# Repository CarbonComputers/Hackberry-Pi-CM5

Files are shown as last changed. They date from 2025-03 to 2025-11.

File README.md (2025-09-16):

<p align="center">
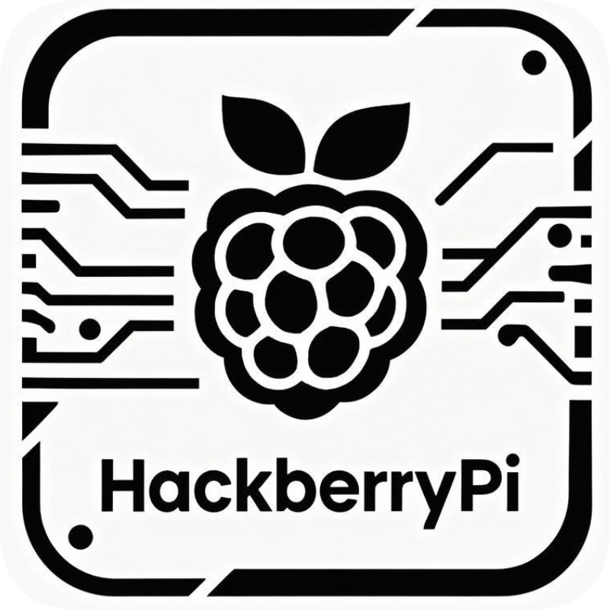
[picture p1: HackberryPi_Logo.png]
Redox logo

 </p>

 <h3 align="center">The HackberryPi_CM5 Project Repo</h3>

<div align="center">

[]()




</div>

---

The HackberryPi CM5 project is a Raspberry Pi Compute Module SBC(single board computer) powered handheld computer with reuse of original keyboard from old Blackberry phones. The goal of the project is to create a portable linux-powered computer that lets the user gain a deeper understanding of Linux and explore the architecture of hardware, software, and the Linux kernel. This repository will be used to share information about the project and tutorial about how to make use of this device.

<p align="center">
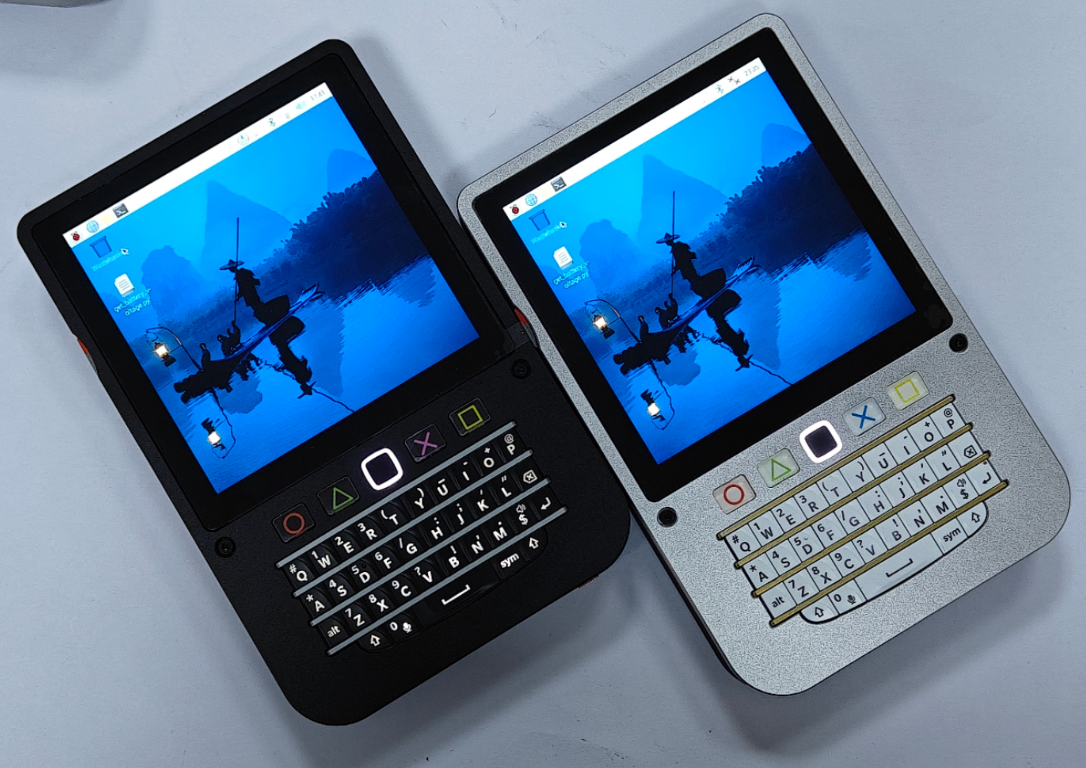
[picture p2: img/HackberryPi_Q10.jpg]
HackberryPi_CM5

</p>

**About the creator bio**: Zitao, currently a master’s student in Mechanical Engineering and Industrial Design at the Technical University of Dresden, Germany  

<div align="center">
 
[Questions or need more info? Join my Discord Channel!](https://discord.gg/WzPthAmMbP)
 
 </div>

  # <a name='Dimension and weight  '>Dimension and weight</a>
  **Overall dimensions:** 143.5x91.8x17.6mm  
  **Weight:** 306 Gramm(with battery,cm5 and heat sink)  
  Upper and lower case made of aluminium  
  Middle part 3d printed  
  <p align="center">
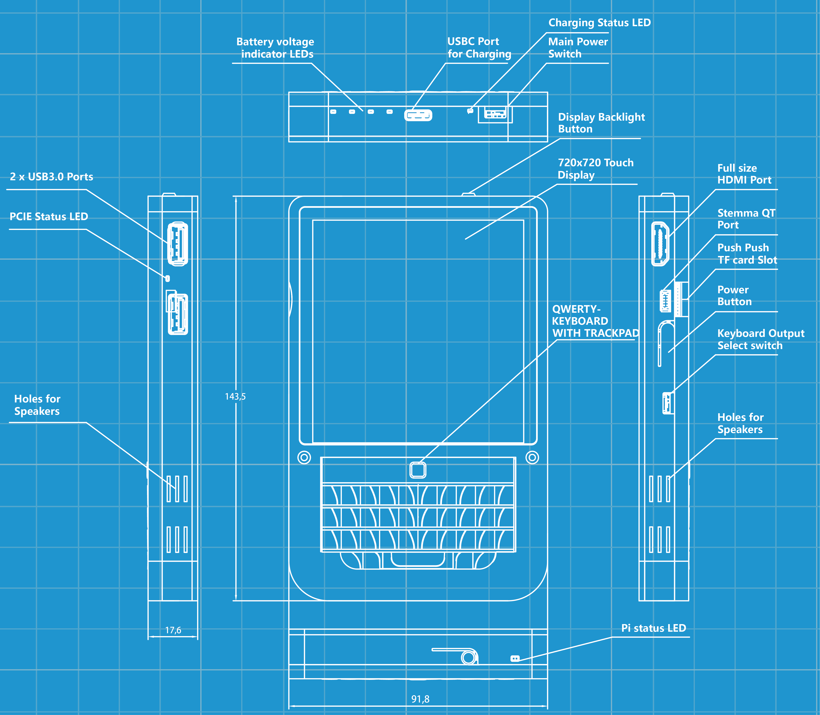
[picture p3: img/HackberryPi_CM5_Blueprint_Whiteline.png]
HackberryPi_CM5_Blueprint

 </p>
 And this is how it looks like inside the device:
  <p align="center">
HackberryPi_CM5_inside
 </p>
 
 # <a name='About this Device '>About this Device </a>

| **Feature** | **Details** |
|---|---|
| **SBC** | Only compatible with Raspberry Pi CM5. [CM5 Datasheet](https://datasheets.raspberrypi.com/cm5/cm5-datasheet.pdf) |
| **CPU** | BCM2712, quad-core Cortex-A76 (ARMv8) 64-bit SoC @ 2.4GHz |
| **Dual Speakers** | Dual speakers connected via Bluetooth. [More information](https://github.com/ZitaoTech/HackberryPiCM5/tree/main/Speakers) |
| **2242 NVME Slot** | Supports 2242 SSD or Halio AI accelerator card. [More information](https://github.com/ZitaoTech/HackberryPiCM5/tree/main/NVME%20Slot) |
| **RTC Battery** | CR927 battery slot for RTC functionality. [More information](https://github.com/ZitaoTech/HackberryPiCM5/tree/main/RTC-Battery) |
| **Metal Body** | Aluminium front and back plate; 3D-printed middle section |
| **Display** | 4" 720x720 high-resolution TFT with multi-touch |
| **USB Ports** | 2x USB 3.0 ports |
| **HDMI Port** | One full-sized HDMI port |
| **Battery Type** | 5000mAh LiPo battery. [More information](https://github.com/ZitaoTech/HackberryPiCM5/tree/main/Battery) |
| **Battery Life** | ~5 hours idle, 3–4 hours typical usage |
| **Battery Voltage Measurement** | I2C-based battery voltage measurement. [More information](https://github.com/ZitaoTech/HackberryPiCM5/tree/main/Battery_Voltage_Measure) |
| **Magnet on Back Plate** | Built-in magnet compatible with iPhone-style wired MagSafe power banks. [More information](https://github.com/ZitaoTech/HackberryPiCM5/tree/main/Magnet%20backplate) |
| **Keyboard Mouse Combo** | On-board combo; supports BlackBerry Q10, Q20, or 9900 keyboard |
| **Custom Keymap** | Configurable via [VIAL](https://get.vial.today/). [More information](https://github.com/ZitaoTech/HackberryPiCM5) |
| **Charging Rate** | 1.5A–2A via Type-C; full charge in 2–3 hours |
| **Stemma I2C Port** | On-board Stemma I2C port for external sensors |

# <a name='3D model  '>3D model</a>
In this page you can find the 3D model of each part of this device, you can print or modify the part yourself.
* [3D model about this device](https://github.com/ZitaoTech/HackberryPiCM5/tree/main/3D-Modell)
  
# <a name='Assembly Guidelines  '>Assembly Guidelines</a>
The HackberryPi_CM5 comes without the CM5 unit. Generally, you only need to install the CM5 and the passive heatsink on top. For details, please refer to this page.
* [Assembly Guidelines](https://github.com/ZitaoTech/HackberryPiCM5/tree/main/Assembly)  

# <a name='Hardware  '>Hardware</a>
This page offers an in-depth hardware overview of the HackberryPi_CM5, designed to guide anyone interested in creating an adapter board for the CM5 module, exploring the keyboard’s hardware architecture, and related concepts. For more details, please visit this page.
* [Hardware](https://github.com/ZitaoTech/HackberryPiCM5/tree/main/Hardware)  

# <a name='Speakers  '>Speakers</a>
There are dual speakers on board, it is needed to pair with the bluetooth audio module to make sound for more information please refer to this page.  
* [Pair with speakers](https://github.com/ZitaoTech/HackberryPiCM5/tree/main/Speakers#pair-with-the-speakers)

# <a name='External antenna  '>External antenna</a>
Because of the metall case and the mounted heat sink, the performance of the original PCB antenna might be a little bit disappointing. This page can tell you how to assemble an external antenna;
* [External antenna](https://github.com/ZitaoTech/HackberryPiCM5/tree/main/External%20Antenna)

# <a name='Gallery  '>Gallery</a>
For more photos of the HackberryPi_CM5, please refer to this page.
* [Gallery](https://github.com/ZitaoTech/HackberryPiCM5/tree/main/Gallery)

# <a name='Where to buy from U.S.A Assembled'>Where to buy from U.S.A Assembled & Ready to use</a>
* [Buy from Carbon Computers](https://carboncomputers.us/)

* Credits to Zitao for creating the ultimate PiBerry build. We are working on a new, slimmer model with phone features, the Cybert.

# <a name='Short video  '>Short video</a>
* [Tiktok: Mr.Hackberry(One friend of mine)](https://www.tiktok.com/@mr.hackberry_pi)

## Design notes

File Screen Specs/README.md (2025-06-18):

# Screen on HackberryPi_CM5

Thanks to raspberrypi fundation that they leave dpi interface on each RaspberryPi, this gives the chance for the pi to drive normal rgb display very easily. More information please check the doc in this page.

On HackberryPi_CM5 there is a 3.95 inch 720*720 resolution RGB666 display with touchscreen on board.

The hardware needed is basically a fpc connector for the display and the backlight light boost circuit to drive 3.3V to around 12V to drive the backlight LEDs.

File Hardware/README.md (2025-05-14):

# The key hardware design features of the HackberryPi_CM5

* DPI display circuit: 40-pin Connector+Display backlight boost circuit: 3.3V->12V
* Bluetooth speaker on board: Basically driverless between different operating system
* Powersource: Powerbank SOC IP5310 provide 5V power + IP5306 for charging
* Keyboard: Keyboard controller RP2040 and communicates with CM5 via USB interface
* CM5 Slots: 2 x DF40C-100DS-0.4V(51)
* Push-push out TF card Slot: quick change between different tf cards
* 2 x USB 3.0 Ports: Use with high speed U-Disk
* M.2 Slot on board: Boot on SSD or use with AI Kit
* USB-KVM circuit for Keyboard: Make the device as emergency keyboard
* Full size HDMI Port: No longer need for mini hdmi adapter!
* Stemma QT port: Connect with I2C sensors
* Battery voltage measure chip on board: Get the current battery voltage
* Reserved fan connector

# BOM file of HackberryPi_CM5

Check the [ibom file](https://github.com/ZitaoTech/HackberryPiCM5/blob/main/Hardware/Bom_HackberryPi_CM5_Q20_rev0.html) of this page to review the component on HackberryPi_CM5


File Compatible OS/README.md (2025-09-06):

# Install different operating system on HackberryPi_CM5

There are many different OS that you can install on HackberryPi_CM5. They are basically those OS that support RaspberryPi5 Serie. 
But note that RaspberryPi5 or BCM2712 is relativly a new chip. Some OS may have not enough support for Pi5 like Kali.  

### On this page, there are many folders that will tell you how to install the driver for this screen on these operating systems.

### If you want to try other OS that is not mentioned in this page. You can try the normal way listed below:

```Step1``` Download the ```vc4-kms-dpi-hyperpixel4sq.dtbo``` and ```hyperpixel4.dtbo``` file in this page  
```Step2``` Put the two files into the ```/overlay/``` folder of the image disk  
```Step3```  Copy and paste the following lines into the ```/boot/config.txt```  
```sh
dtoverlay=vc4-kms-v3d
dtoverlay=vc4-kms-dpi-hyperpixel4sq
```
In this way, you have installed the screen driver on this operating system and invoked it.  
Unless this operating system does not support the Pi 5, it should generally be able to display the image on this screen.

### Also note that the default hardware I2C and SPI gpios are used for the display. So remember to disable them in the OS

# Fix shifted pixel at first col

You might see there is shifted pixel at the first col of the display like this:


Here is the solution to fix that:

```Step1``` Download the ```hackberrypi.dtbo``` file in this page   
```Step2``` Put the file into the ```/overlay``` folder of the image disk   
```Step3``` Delete ```dtoverlay=vc4-kms-dpi-hyperpixel4sq``` and paste the following into the ```/boot/config.txt```  
```sh
dtoverlay=hackberrypi
```

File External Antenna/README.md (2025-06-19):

# External antenna on HackberryPi_CM5

In my experiments, the signal from the PCB antenna on the Raspberry Pi CM5 module may not be ideal when a passive aluminum heatsink is installed. Therefore, adding an external antenna can sometimes enhance the signal strength of the CM5.
The following are the installation steps:

### Install external antenna on HackberryPi_CM5

```Step1:``` Loosen the four screws on the back panel.  
```Step2:``` Connect the external FPC antenna with a first-generation IPEX connector to the antenna socket on the Raspberry Pi CM5 board.  
```Step3:``` Adjust the direction of the antenna to prevent interference with the enclosure, as shown in the picture:  
```Step4:``` Add a line of code in the config.txt file by 
```sh
sudo nano /boot/firmware/config.txt
```

with the following line
```sh
dtparam=ant2
```
Source: [CM5 datasheet](https://datasheets.raspberrypi.com/cm5/cm5-datasheet.pdf)  
Now you can have a better signal experience.



#### You can buy the external antenna with HackberryPi_CM5 together on elecrow:  
[Buy from elecrow](https://www.elecrow.com/external-fpc-antenna-for-hackberrypi-cm5.html)

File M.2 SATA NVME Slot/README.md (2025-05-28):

# NVME Slot on HackberryPi_CM5

There is an NVME Slot on board which is only compatible with 2242 ssd or hailo 8 AI accelerator card.

There are many types of ssd that are not compatible with RaspberryPi, it is recommended to buy the ssd directly from shop of elecrow:

## Use SSD with HackberryPi_CM5

### Enable PCIe
First enable PCIe Interface, note: PCIE interface is enabled on the PI5B by default.
If the PCIE interface is not enabled, you add the following content in "/boot/firmware/config.txt" by typing ```sudo nano /boot/firmware/config.txt``` in a terminal:
```sh
dtparam=pciex1
```
at [all] section

The default mode of PCIe is gen2. If you need to enable PCIe Gen3, you need to add the following content at /boot/firmware/config.txt:
```sh
dtparam=pciex1_gen=3
```
at [all] section

Now the ```config.txt``` file will look like this:  


Now make a ```sudo reboot``` and type ```lsblk``` The SSD should be recognized by the Pi:


### Partition
```sh
sudo fdisk /dev/nvme0n1
```
Execute n to add the partition, and then just type enter enter enter until a new partition is created, and then execute w to save and exit.
3e1775b2937b64a7e02af512a7da948c

### Format
```sh
sudo mkfs.vfat -F 32 /dev/nvme0n1p1
```
Wait for a few moments, when done has appeared, it means that the formatting has been carried out.
1a0374a7-da44-4201-9268-f5ef6763b0c1

### Mount
Create Mount Directory(Use any name)
```sh
sudo mkdir ssd
```
Mount the device
```sh
sudo mount /dev/nvme0n1p1 ./ssd
```
Checking disk status
```sh
df -h
```


## Read/Write Test
Enter the directory where the disk is mounted:
```sh
cd ssd
```
Write test
```sh
sudo dd if=/dev/zero of=./test_write count=2000 bs=1024k
```
Read Test
```sh
sudo dd if=./test_write of=/dev/null count=2000 bs=1024k
```
Note: Different cards and environments make different test results. As the Raspberry Pi is more vulnerable to being affected, if you want to test the exact performance, you can use a PC to test.


## Auto-Mounting
If the testing is sound and you don't need it as a system disk and only use an extended disk, you can set up an automatic mounting.
```sh
sudo nano /etc/fstab
```
#Add the following content at the end:
```sh
/dev/nvme0n1p1  /home/pi/ssd  ext4  defaults  0  0
```
#/dev/nvme0n1p1 is the device name, /home/pi/ssd is the directory to be mounted, ext4 is the file system type, defaults are using the default mounting setting  
Make the modification take effect (make sure the test is sound before rebooting, otherwise it will lead to failure to mount or boot; if it cannot boot, you can remove the content added in /etc/fstab)
```sh
sudo mount -a
```
You should see an external disk on the desktop after reboot

## Booting from NVMe SSD
Open Menu->Accessories->SD card Copier.  
  
Copy the image from SD card to SSD:  
  
Wait a few moment until the copying is finished.  
  

Then
```sh
sudo rpi-eeprom-config --edit
```
Modify BOOT_ORDER=0xf41 as BOOT_ORDER=0xf416  


Remove the tf card and reboot the HackberryPi then the system should be rebooted from the SSD, it's about 10 seconds faster than booting from tf card(RaspberryPi OS)

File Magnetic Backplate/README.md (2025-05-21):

# Magnet at the backplate on HackberryPi_CM5

There is magnet at the backplate just like the one on iphone



With this magnet the HackberryPi_CM5 can be attatched to any phone stand compatible with Magsafe or powerbank

Magnet backplate


Where to buy the phone stand in the gif:
[buy from elecrow](https://www.elecrow.com/phone-stand-for-hackberrypi-cm5.html)

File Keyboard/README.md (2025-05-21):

# Keyboard on HackberryPi_CM5

There are currently 3 versions of keyboards for HackberryPi_CM5: Q10 Q20 and 9900 keyboards

Different keyboard has its own style

* Q10: Q10 keyboard has linear layout and the keycap is slightly smaller than the Q20, the original Q10 keyboard has no top row keys and trackpad, I use the trackpad from 9900 and add another top row keys with PS game controller icon on it.
* Q20: Q20 keyboard has linear layout and has the largest keycap, but there the trackpad on Q20 keyboard is the smallest and it has no backlight around the trackpad.
* 9900: 9900 keyboard has ergonomic smile layout, the keycap is the smallest one. 

# Keyboard function on HackberryPi_CM5

Each keyboard has the same keycap number and the trackpad can be used as mouse and also scroll wheel when capslock is enabled, when capslock is enabled the trackpad backlight on Q10 and 9900 will be lighted on while on Q20 the top row keys backlight will be lighted on.

Each keyboard backlight can be adjusted with 10 steps.

When hold Ctrl, mouse dpi /2 and while hold Alt, mouse dpix2.

# How to use the .vil file?  
Let's say that you changed many keycodes and want to reset the keyboard layout  
First download vial app from [vial](https://get.vial.today/) homepage  
Install the vial app and open the app  
Then connect yor computer with Hackberry and in menu **file**->**Load saved layout** and select the .vil file, the keyboard layout will be reset.  

# Default Layout and Layers
### Layer0:
Keymap_Layer0

### Layer 1:
Keymap_Layer1

### Layer 2:
Keymap_Layer2

# Customize the keymap

Thanks to the qmk firmware running on the keyboard, each key on HackberryPi_CM5 can be remapped on [vial app](https://get.vial.today/), just need to connect the HackberryPi with another computer via the usbc port below and flip the left switch and the keyboard output will be changed and the computer will recognize the keyboard on vial app. 

# Some features you can use in via app

### Tap dance
You can set each key on the keyboard on each layer to trigger some keycode with single tap, double tap or hold in tapdance


### Macros
You can use record function in vial app and output a lot of text using macros function

For more information please refer to the user manual on [vial page](https://get.vial.today/manual/)

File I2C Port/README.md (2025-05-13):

# I2C port on HackberryPi_CM5

There is one stemma qt port on board, it can be used to communicate with other I2C interface sensor.

Default I2C bus number on HackberryPi_CM5: 11

***Example:***

Use with DHT20 Sensor:

```sh

import time
import smbus2

address = 0x38  # DHT20 I2C address

# Initialize the I2C bus (usually bus 1 on Raspberry Pi)
i2cbus = smbus2.SMBus(11)
time.sleep(0.5)  # Allow sensor to power up

while True:
    # Read a status byte to check initialization
    data = i2cbus.read_i2c_block_data(address, 0x71, 1)
    if (data[0] | 0x08) == 0:
        print('Initialization error')
    else:
        # Trigger a measurement by writing the command
        i2cbus.write_i2c_block_data(address, 0xac, [0x33, 0x00])
        time.sleep(0.1)  # Give sensor time to perform measurement

        # Read 7 bytes of data from the sensor
        data = i2cbus.read_i2c_block_data(address, 0x71, 7)

        # Calculate raw temperature and convert to °C
        Traw = ((data[3] & 0x0F) << 16) | (data[4] << 8) | data[5]
        temperature = 200 * float(Traw) / (2**20) - 50

        # Calculate raw humidity and convert to %RH
        Hraw = ((data[3] & 0xF0) >> 4) | (data[1] << 12) | (data[2] << 4)
        humidity = 100 * float(Hraw) / (2**20)

        print("Temperature: {:.2f}°C, Humidity: {:.2f}%".format(temperature, humidity))

    # Wait for 1 second before the next reading
    time.sleep(1)

```



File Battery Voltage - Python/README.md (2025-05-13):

# Battery voltage measure on HackberryPi_CM5

There is a microchip on board that can measure the current battery voltage called MAX17048.

It communicates with the CM5 via I2C interface  

With the simple python code below the HackberryPi_CM5 can measure the current battery voltage for example in thonny  
```sh
import smbus2
import time

class MAX17048:
    def __init__(self, i2c_bus=11, i2c_address=0x36):
        self.bus = smbus2.SMBus(i2c_bus)
        self.address = i2c_address

    def read_voltage(self):
        try:
            # Read voltage registers (0x02 and 0x03)
            read = self.bus.read_i2c_block_data(self.address, 0x02, 2)
            
            # Combine the bytes and convert to voltage
            voltage_raw = (read[0] << 8) | read[1]
            voltage = voltage_raw * 0.078125  # 78.125μV per LSB
            
            return voltage / 1000  # Convert to volts
            
        except Exception as e:
            print(f"Error reading voltage: {e}")
            return None

    def close(self):
        self.bus.close()

if __name__ == "__main__":
    max17048 = MAX17048()
    
    try:
        while True:
            voltage = max17048.read_voltage()
            if voltage is not None:
                print(f"Battery Voltage: {voltage:.2f} V")
            time.sleep(1)
            
    except KeyboardInterrupt:
        print("\nProgram stopped")
        max17048.close()
```



# Hardware

This is the schematic of the battery voltage measure part on HackberryPi_CM5  

  

The battery voltage measure chip and the screen’s touch controller are on the same I2C bus on HackberryPi_CM5.

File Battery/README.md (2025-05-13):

# Battery on HackberryPi_CM5

The battery used on HackberryPi_CM5 is Lipo battery with multiple certifications

```Dimension```: 83x50.5x10.1mm  
```Capacity```: 5000mah @ 3.7V, 18.5Wh  
```Battery Voltage```: 2.75-4.2V  
```Weight```: 84.4g  
```Connector```: PH2.0 2P  
```Battery overcurrent protection```: 5A

# Battery Foto
![image](https://github.com/user-attachments/assets/dd967207-a15c-49b6-8718-a3090722f99e)

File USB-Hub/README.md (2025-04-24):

# USBHub for HackberryPi_CM5

There is an USBHub for HackberryPi_CM5 which can extend one of the USB3.0 Port on HakcberryPi_CM5 into 3 USB2.0 Ports and 1 USB3.0 Port. It's made of Aluminium case and it's very lightweighted. 



⚠️ **Note:**  
This USBHub can comsumpe approximately 60-70ma @5V so it will add about 0.3-0.4W power consumption.

#### You can buy this USBHUB together with HackberryPi_CM5 on elecrow

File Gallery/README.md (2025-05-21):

### HackberryPi_CM5 get DHT20 reading 
<p align="center">
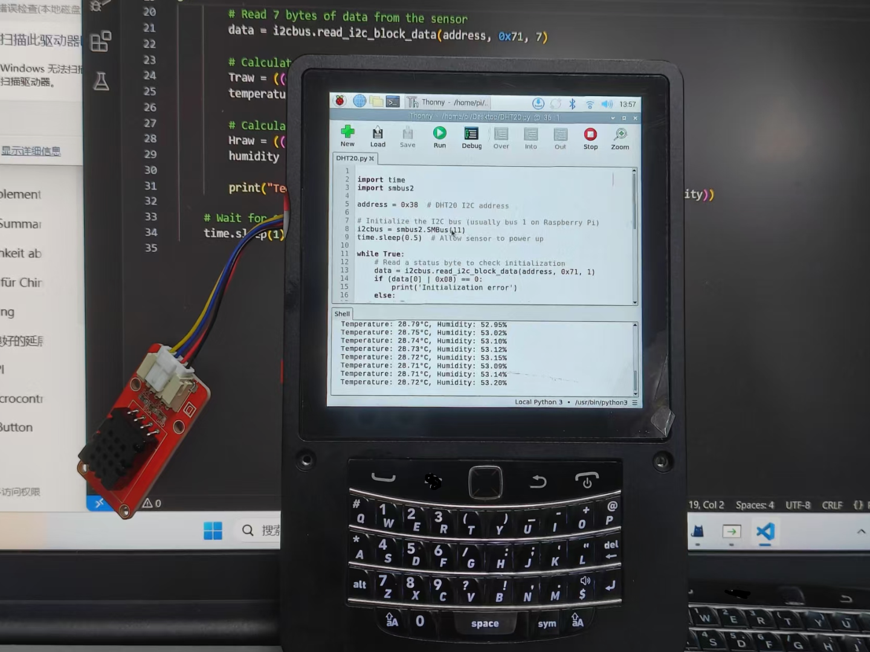
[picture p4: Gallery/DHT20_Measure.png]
HackberryPi_CM5_read_DHL20

</p>

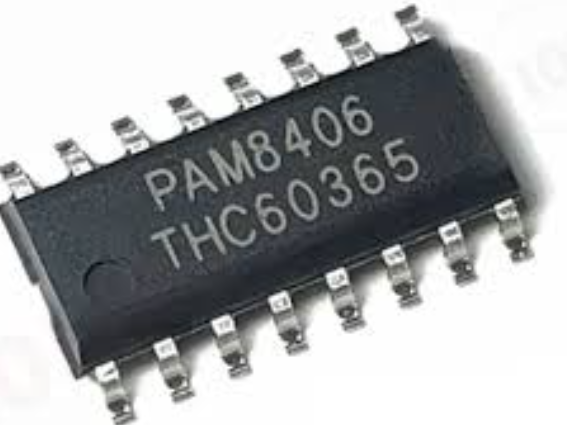
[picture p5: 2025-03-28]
Speakers/PAM8406.png

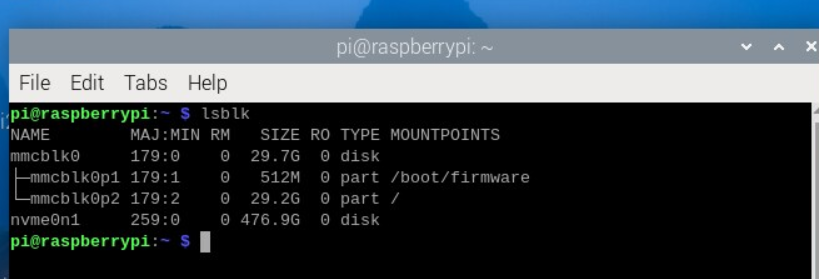
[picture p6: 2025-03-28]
M.2 SATA NVME Slot/SSD recognize.png

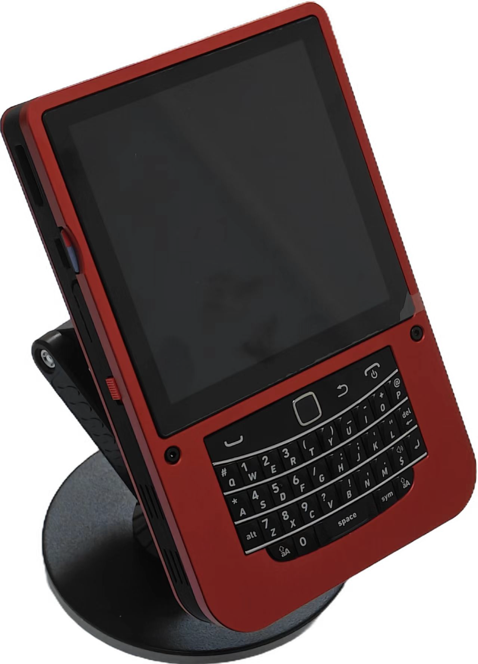
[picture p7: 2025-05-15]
Gallery/Magnet_HackberryPi_1.png

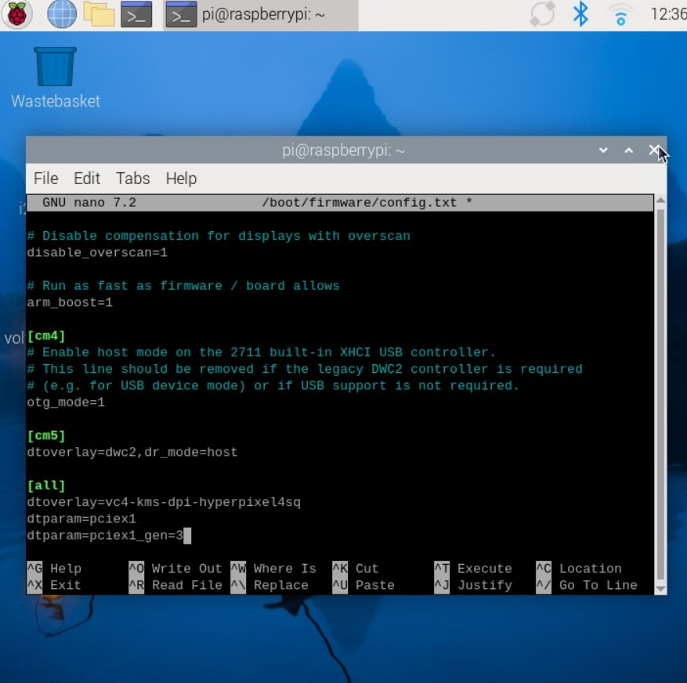
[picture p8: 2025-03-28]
M.2 SATA NVME Slot/Enable PCIE.png

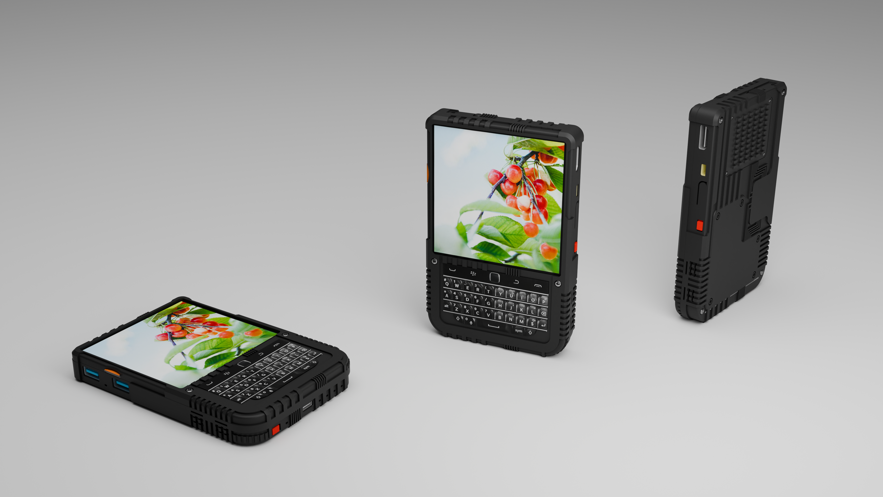
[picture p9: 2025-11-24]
3D-Model/CyberPunk Case/HP CM5 Cyberpunk Black.png

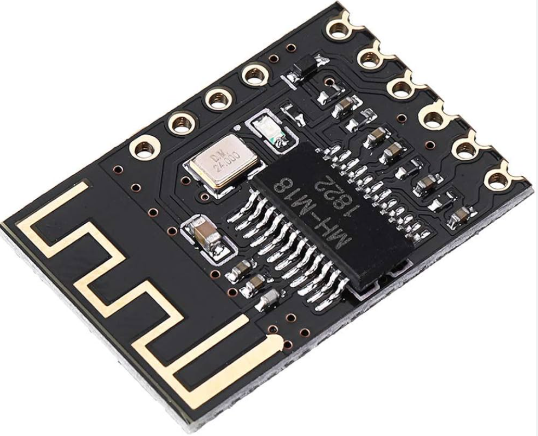
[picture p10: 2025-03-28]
Speakers/Bluetooth Audio Module.png

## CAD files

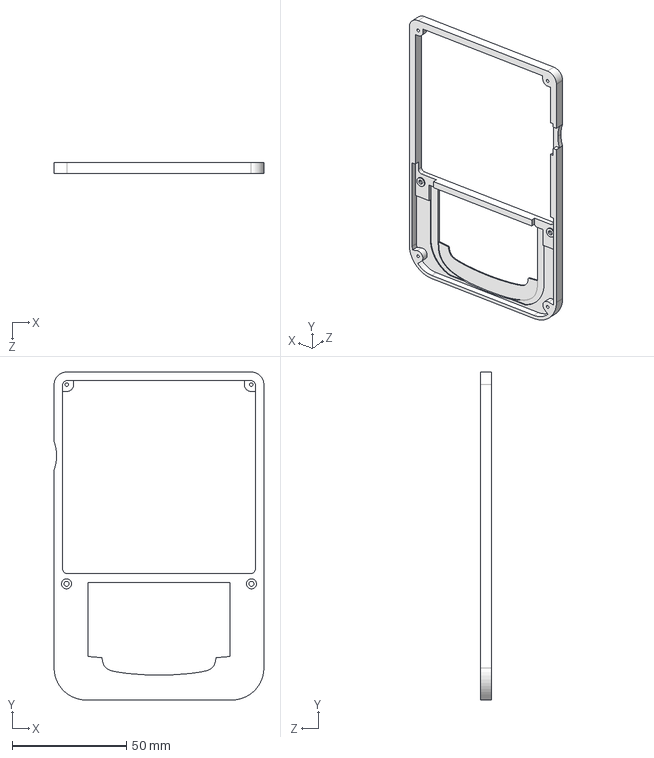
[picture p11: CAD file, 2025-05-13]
3D-Model/9900 version/HackberryPi_CM5_9900_Uppercase.STEP
91.8 x 143.5 x 5.00 mm

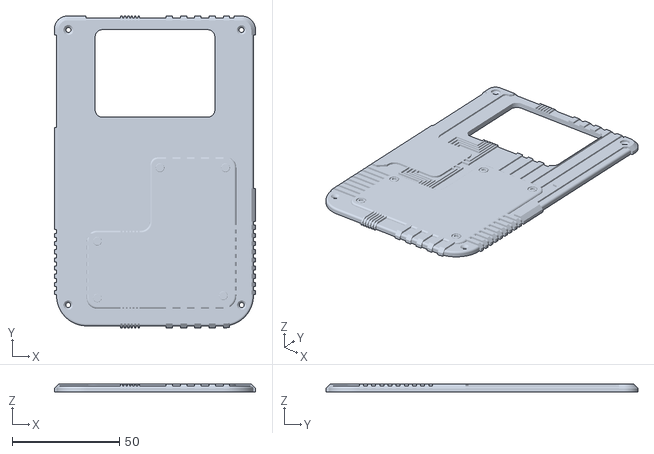
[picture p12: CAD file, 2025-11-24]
3D-Model/CyberPunk Case/lower_part_v1_rev1.stl
93.8 x 145.5 x 3.70

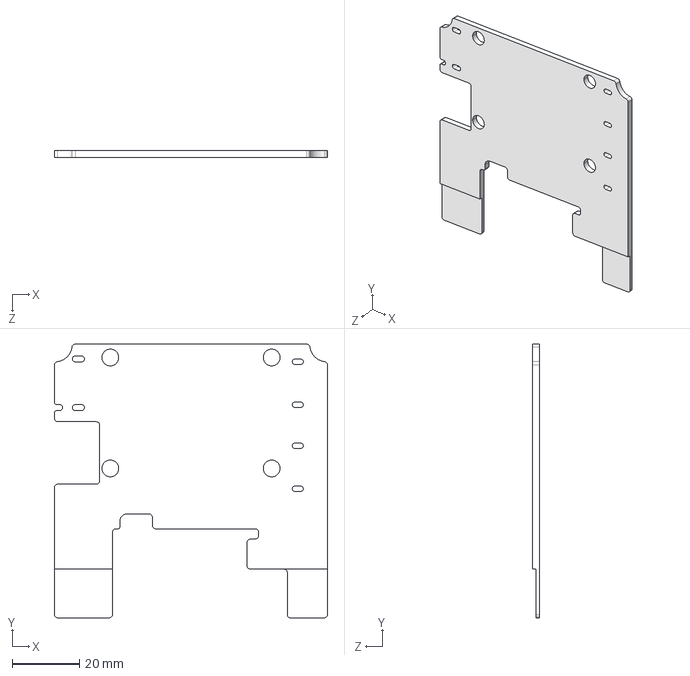
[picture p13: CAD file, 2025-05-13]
3D-Model/HackberryPi_CM5_Displaysupport.STEP
81.2 x 81.4 x 2.10 mm

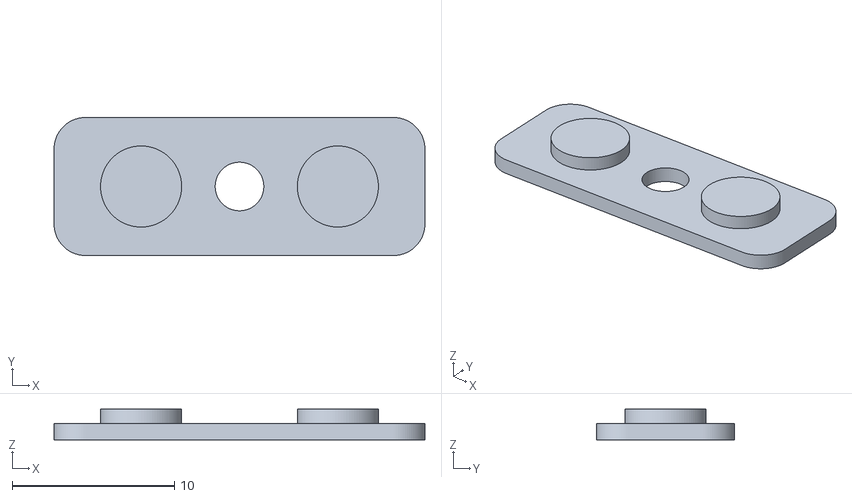
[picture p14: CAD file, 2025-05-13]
3D-Model/Q10 version/HackberryPi_CM5_Q10_Toprowkeys_Support.stl
22.9 x 8.51 x 1.90

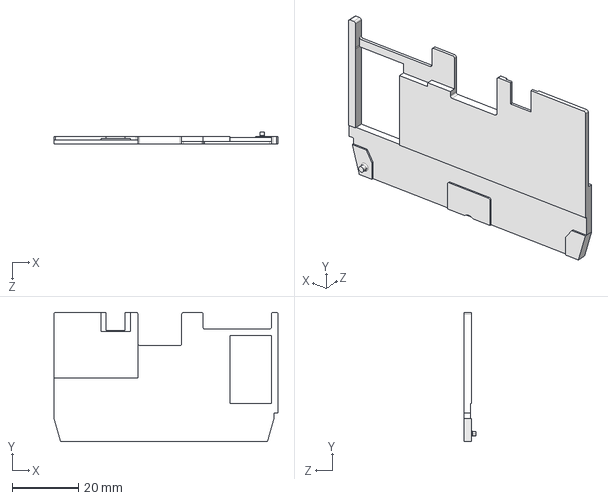
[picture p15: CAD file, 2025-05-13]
3D-Model/Q20 version/HackberryPi_CM5_Q20_Keyboard_Support.STEP
67.8 x 39.1 x 3.60 mm

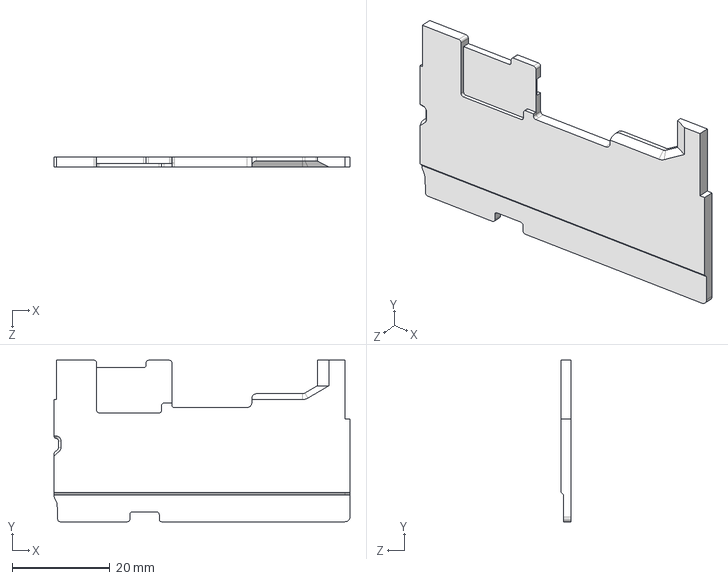
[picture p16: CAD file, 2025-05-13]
3D-Model/9900 version/HackberryPi_CM5_9900_KeyboardSupport.STEP
60.5 x 33.0 x 2.00 mm

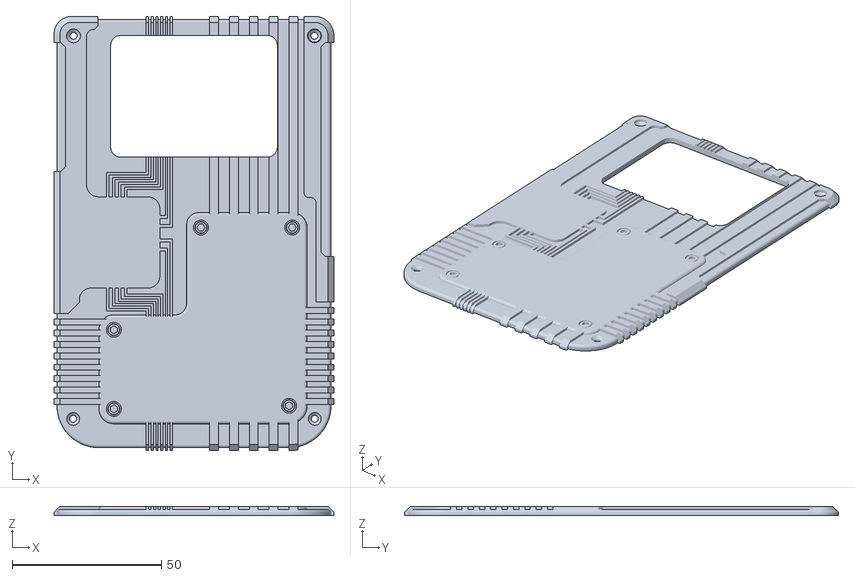
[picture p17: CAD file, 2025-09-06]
3D-Model/CyberPunk Case/lower_part_v1.stl
93.8 x 145.5 x 3.00

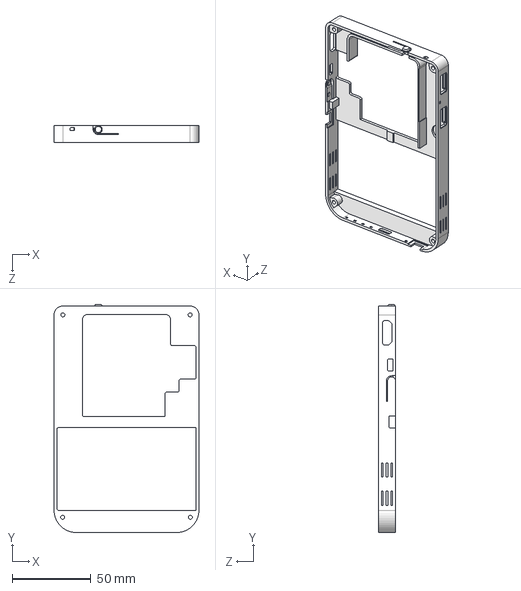
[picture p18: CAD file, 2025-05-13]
3D-Model/HackberryPi_CM5_Middlepart.STEP
91.8 x 144.5 x 10.6 mm

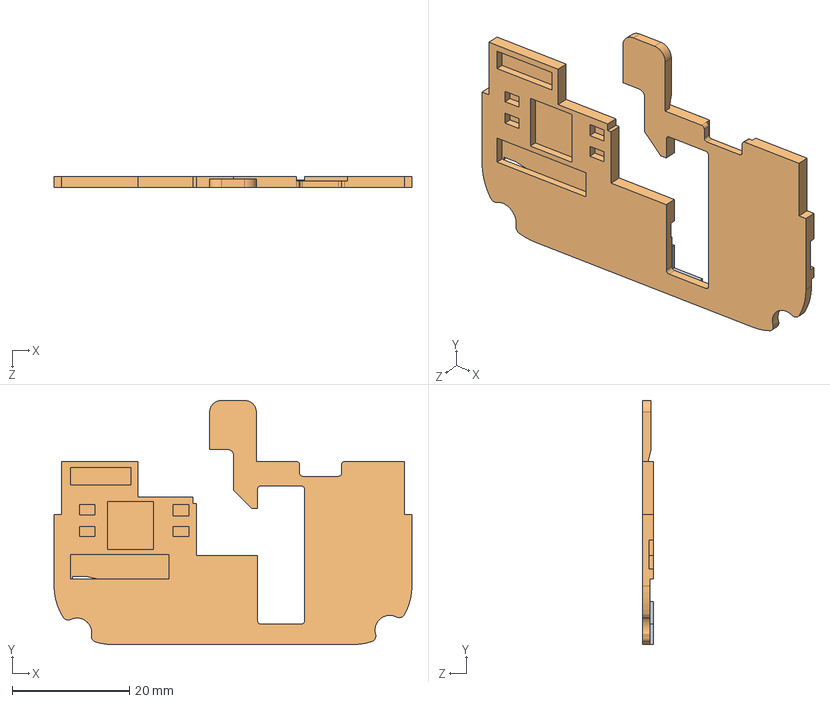
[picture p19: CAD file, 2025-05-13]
3D-Model/Q10 version/HackberryPi_CM5_Q10_KeyboardSupport.STEP
61.0 x 41.6 x 1.95 mm

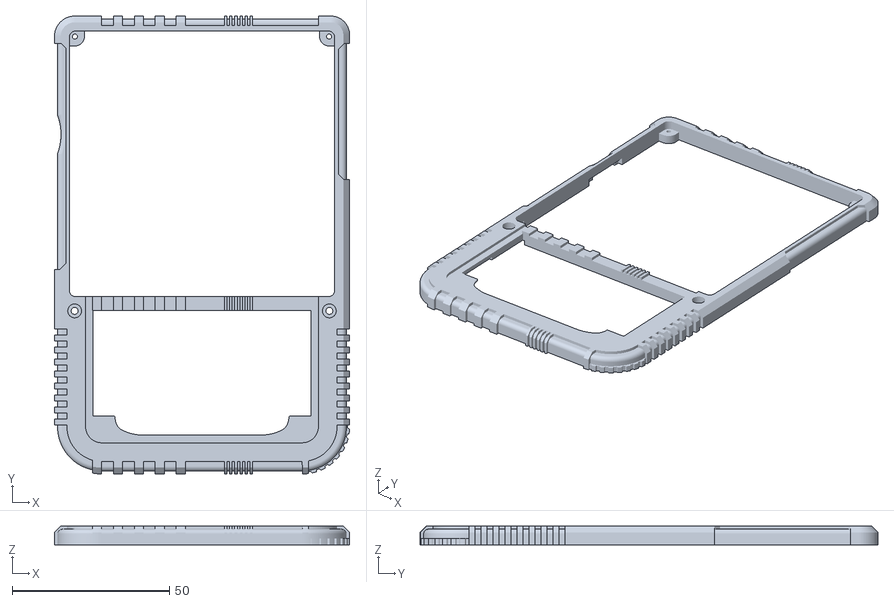
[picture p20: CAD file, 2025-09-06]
3D-Model/CyberPunk Case/Q20_upper_part_v1.stl
93.8 x 145.5 x 6.00

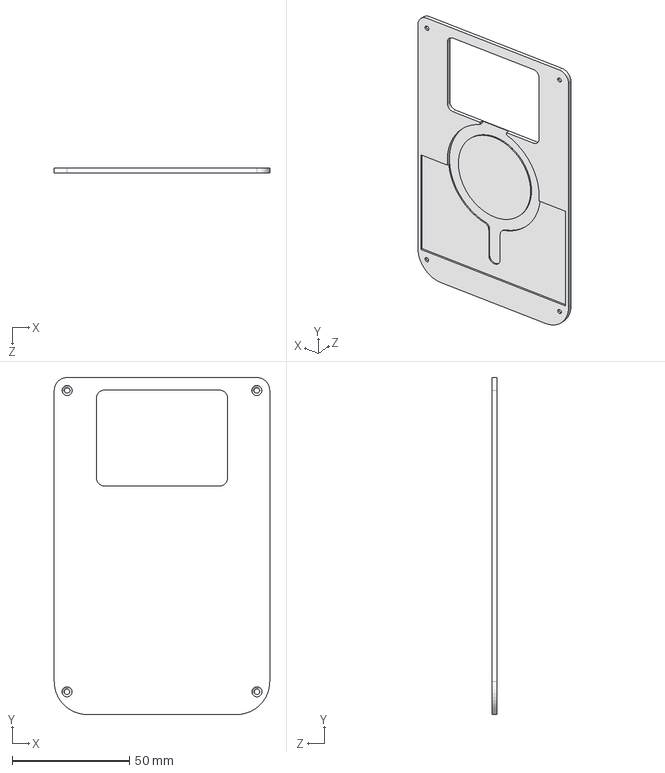
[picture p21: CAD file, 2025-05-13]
3D-Model/HackberryPi_CM5_Lowercase.STEP
91.8 x 143.5 x 2.00 mm

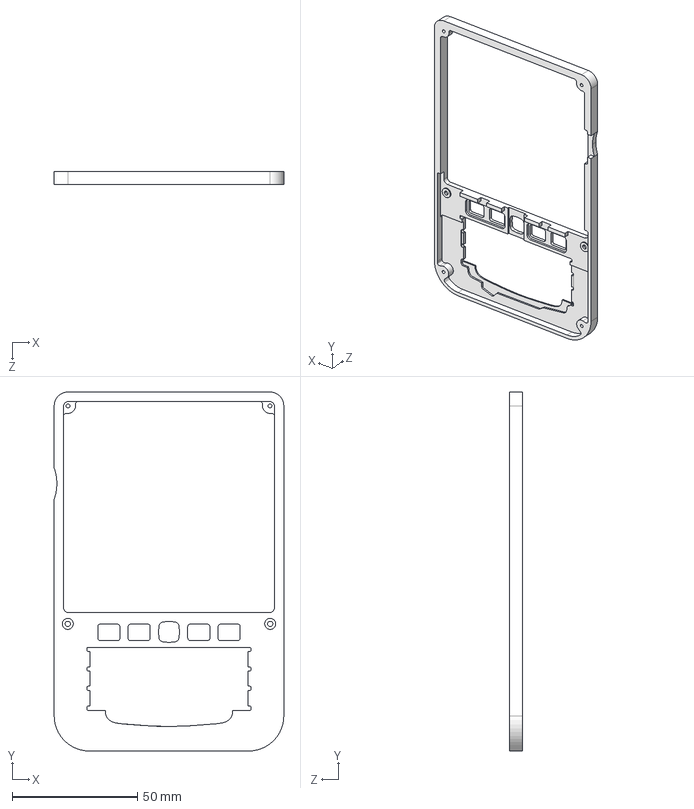
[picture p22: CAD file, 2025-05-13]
3D-Model/Q10 version/HackberryPi_CM5_Q10_uppercase.STEP
91.8 x 143.5 x 5.00 mm

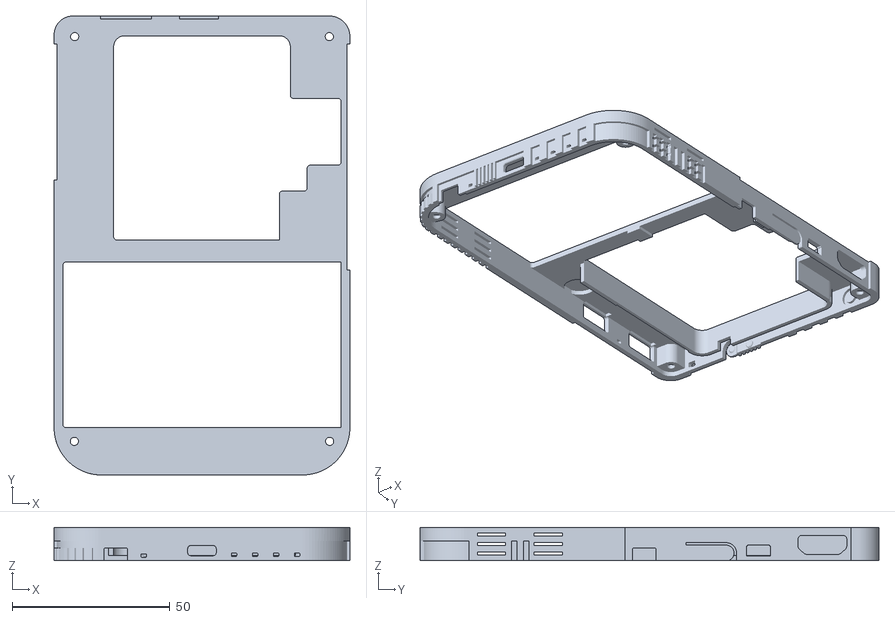
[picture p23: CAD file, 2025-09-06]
3D-Model/CyberPunk Case/middle_part_v1.stl
93.8 x 145.5 x 10.6

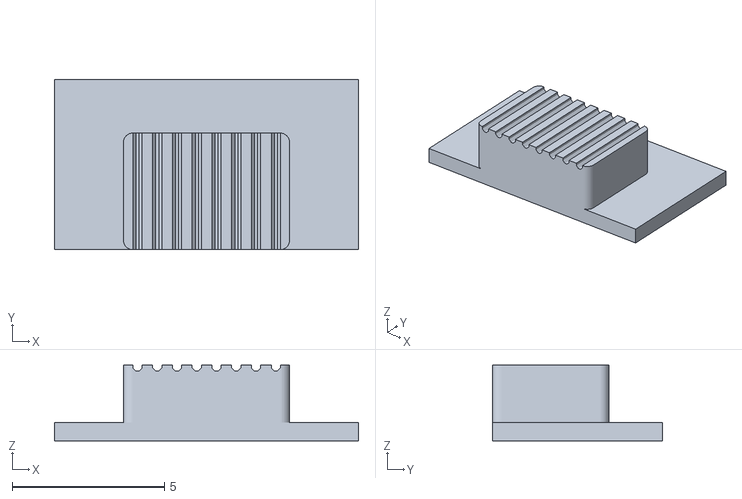
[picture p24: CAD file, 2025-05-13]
3D-Model/HackberryPi_CM5_Redswitch.STL
10.0 x 5.60 x 2.49

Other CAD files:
Mechnical Drawing/HackberryPi_CM5_mechanical_drawing.DWG
3D-Model/Q20 version/HackberryPi_CM5_Q20_Uppercase.STEP
3D-Model/HackberryPi_CM5_White_Screwtool.STL
3D-Model/9900 version/HackberryPi_CM5_9900_Keyboard_Support.stl
3D-Model/9900 version/HackberryPi_CM5_9900_Uppercase.stl
3D-Model/HackberryPi_CM5_Displaysupport.STL
3D-Model/HackberryPi_CM5_Lowercase.STL
3D-Model/HackberryPi_CM5_Middlepart.STL
3D-Model/Q10 version/HackberryPi_CM5_Q10_Keyboard_Support.stl
3D-Model/Q10 version/HackberryPi_CM5_Q10_uppercase.STL
3D-Model/Q20 version/HackberryPi_CM5_Q20_Keyboard_Support.STL
3D-Model/Q20 version/HackberryPi_CM5_Q20_Uppercase.STL

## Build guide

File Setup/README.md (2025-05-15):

# Basic setup for HackberryPi_CM5

### How to make sound

There is bluetooth speaker on board on HackberryPi_CM5, you need to pair with the bluetooth module on board to make sound. More detail please refer to this [page](https://github.com/ZitaoTech/HackberryPiCM5/tree/main/Speakers)

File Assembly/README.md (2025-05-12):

## Assembly Guidelines of the HackberryPi_CM5

Assembly is straightforward: install the CM5 module, secure the heat sink,, here are the steps for the assembly

### Firstly, disassemble the back plate with the screw driver in the box


### Secondly put the Compute module5 on the slot 


### Then use the white printed tool to secure the yellow screws



### Don't forget this: Place the thermal silicone pad onto the CM5 module.


### At last secure the heat sink with screws and lock the back plate.



Now it's OK to turn on the device and enjoy your time with it!!!

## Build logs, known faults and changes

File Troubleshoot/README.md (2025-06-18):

# Troubleshoot of HackberryPi_CM5

### Keyboard has no reaction

Once you find the keyboard of HackberryPi_CM5 can't type and the trackpad has no reaction to mouse sweep. First check if the left red switch is on the right position. More information about the switch can be found in this page. If the keyboard is at the right position, maybe the keyborad is set into bootloader mode manually. Check if the is one U-Disk found by the pi at desktop. If there is, just reboot the device and the keyborad can get back into function.

### Trackpad no reaction to mouse sweep

When you troubleshoot the second situation and still found the trackpad has no reaction to your finger, try to reboot first and see if the trackpad comes back. If not, please contact me

### There are lines on the screen

Maybe after you boot the device up and found the display showing some lines as the picture shows below, don't worry that you may have broken the display. This is an effect called display polarized, it always happens when the display driver chip is powered on while there is no display image input, you can first disable the power saving or screensaving function in your operating system and put the device running like one hour and the display can revocer itsself.

### Black screen

Make sure to disable the hardware I2C and SPI because the gpios are used by the screen, you can connect the device with external Display with HDMI port to configure the hardware I2C or SPI usage.

### HackberryPi_CM5 won't boot.

1. Boot with TF card: You may find that the device won't boot up after some usage. There is one status LED showing the current status on top of the HackberryPi_CM5. If the white LED won't blink after you blink, that means the kernel image might break down. You need to flash a new image into the tf card or the tf card is broken and you need to use another new card.
2. Boot with SSD: Make sure that the image is stored at the p1 partition(like nvme0n1p1 not nvme0n1p2), otherwise there is a chance that the device can't boot with the image at p2

### No sound 

The speakers are controlled by a bluetooth audio module and it's so you can pair with the audio module via bluetooth. But in some operating system you need to connect the pi with the module maunally after you pair with it.

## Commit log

2025-06-26 Minor spell
    [HackberryPi_CM5_9900_KeyboardSupport.STEP, HackberryPi_CM5_9900_Keyboard_Support.stl, HackberryPi_CM5_9900_Uppercase.STEP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]
2025-06-26 updated links and folder structure
    [HackberryPi_CM5_9900_KeyboardSupport.STEP, HackberryPi_CM5_9900_Keyboard_Support.stl, HackberryPi_CM5_9900_Uppercase.STEP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]
2025-09-06 Adding files for Q20, Cyberpunk case and updated dtbo drivers
    [HackberryPi_CM5_Q20_Keyboard_Support.STEP, HackberryPi_CM5_Q20_Keyboard_Support.STL, HackberryPi_CM5_Q20_Uppercase.STEP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]
2025-11-24 updated cyberpunk case
    [lower_part_v1_rev1.stl]

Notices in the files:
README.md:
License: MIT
